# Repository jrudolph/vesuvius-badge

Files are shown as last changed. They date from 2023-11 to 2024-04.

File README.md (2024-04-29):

# Vesuvius First Word Badge - Hardware Design Files (for Kicad)

First Word Flickering

This repository contains the hardware design files for the Vesuvius First Word Badge badge that displays the first word found in burnt papyrus scrolls
analyzed for the [Vesuvius Challenge](https://scrollprize.substack.com/p/first-word-discovered-in-unopened).

Read more about the hardware of the badge in this [blog post](https://vesuvius.virtual-void.net/blog/2024/01/10/vesuvius-badge-hardware/). The Pico-based
firmware can be found in [vesuvius-badge-pico](https://github.com/jrudolph/vesuvius-badge-pico).

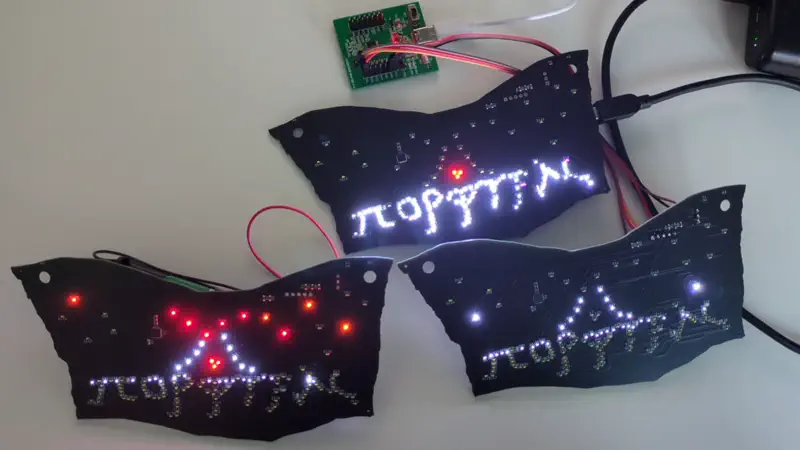
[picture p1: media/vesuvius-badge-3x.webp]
First Word Badge


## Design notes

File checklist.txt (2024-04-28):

 - footprints of leds
 - proper wiring of RPi
 - proper wiring of ch32v003
 - voltage parity between ch32v003 and is chip
 - check minimum voltage for white leds
 - check gerbers

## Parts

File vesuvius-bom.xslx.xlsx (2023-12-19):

Comment | Designator | Footprint | JLCPCB Part#(optional)
IS31FL3731-QF | U1 | QFN-28 | C191206
10uF | C1, C2 | 0402_C | C15525
100nF | C3 | 0402_C | C23024
10k | R1, R2, R3, R4 | 0603_R | C25804
15k | R5 | 0603_R | C22809
20k | R6 | 0603_R | C4184
white | D1-119 | 0402_LED | C917191
red | D120-129 | 0402_LED | C779449
purple | D130-139 | 0603_LED | C7371898
yellow | D140-144 | 0402_LED | C965796

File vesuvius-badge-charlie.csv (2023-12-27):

Comment | Designator | Footprint | LCSC
10uF | C1,C2 | Capacitor_SMD:C_0402_1005Metric | C15525
100nF | C3 | Capacitor_SMD:C_0402_1005Metric | C1525
LED white | D1,D2,D3,D4,D5,D6,D8,D9,D11,D12,D15,D17,D18,D20,D21,D22,D24,D25,D26,D27,D28,D29,D31,D33,D34,D35,D36,D37,D40,D41,D42,D44,D45,D47,D49,D50,D51,D53,D54,D55,D56,D57,D58,D59,D60,D61,D62,D63,D64,D66,D67,D68,D69,D70,D71,D72,D73,D74,D75,D76,D77,D79,D81,D82,D83,D84,D85,D86,D87,D89,D90,D91,D92,D93,D94,D95,D96,D97,D98,D99,D100,D101,D102,D103,D104,D105,D106,D108,D109,D110,D111,D112,D113,D114,D116,D117,D118,D119,D120,D121,D122,D123,D124,D125,D126,D127,D129,D130,D131,D132,D133,D134,D135,D136,D137,D138,D139,D140,D141,D143,D144 | LED_SMD:LED_0402_1005Metric | C965796
LED purple | D10,D13,D19,D38,D43,D52,D65,D88,D107,D115 | LED_SMD:LED_0603_1608Metric | C7371898
LED orange | D30,D39,D46,D78,D128 | LED_SMD:LED_0402_1005Metric | C779448
LED red | D7,D14,D16,D23,D32,D48,D80,D142 | LED_SMD:LED_0402_1005Metric | C779449
Fuse_Small | F1 | Fuse:Fuse_0402_1005Metric | C136320
MountingHole | H1,H2 | MountingHole:MountingHole_5.3mm_M5
Conn_01x05 | J1 | Connector_PinHeader_2.54mm:PinHeader_1x05_P2.54mm_Vertical
Conn_01x03 | J2 | Connector_PinHeader_2.54mm:PinHeader_1x03_P2.54mm_Vertical
SolderJumper_2_Open | JP1,JP3,JP4 | Jumper:SolderJumper-2_P1.3mm_Open_Pad1.0x1.5mm
SolderJumper_2_Bridged | JP2 | Jumper:SolderJumper-2_P1.3mm_Bridged_Pad1.0x1.5mm
4k7 | R1,R2 | Resistor_SMD:R_0603_1608Metric | C23162
10k | R3,R4 | Resistor_SMD:R_0603_1608Metric | C25804
15k | R5 | Resistor_SMD:R_0603_1608Metric | C22809
20k | R6 | Resistor_SMD:R_0603_1608Metric | C4184
IS31FL3731-QF | U1 | Package_DFN_QFN:QFN-28-1EP_4x4mm_P0.4mm_EP2.3x2.3mm | C191206
Pico | U2 | MCU_RaspberryPi_and_Boards:RPi_Pico_SMD
CH32V003J4M6 | U3 | Package_SO:SOP-8_3.9x4.9mm_P1.27mm

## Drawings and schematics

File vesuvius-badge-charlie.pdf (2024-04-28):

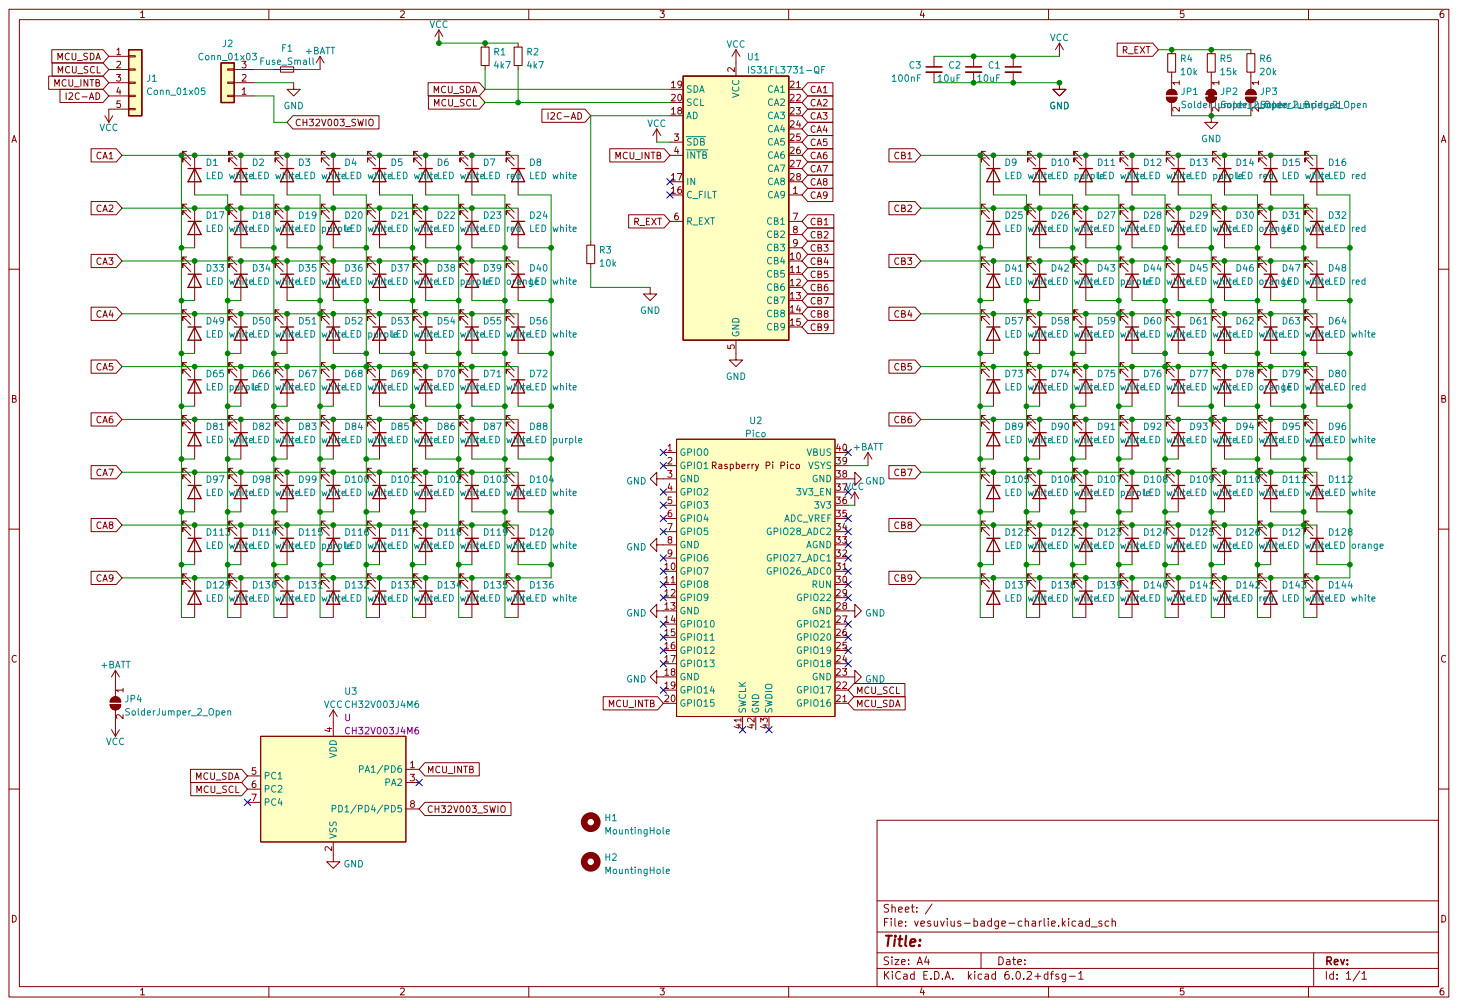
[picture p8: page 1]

2 SCL 20 CA1 21 CA2 22 CA3 23 CA4 24 CA5 25 CA6 26 CA7 27 CA8 28 ~{SDB} 3 ~{INTB} 4 GND

LED white GND GND

File: vesuvius-badge-charlie.kicad_sch Sheet: /
Id: 1/1 Title:

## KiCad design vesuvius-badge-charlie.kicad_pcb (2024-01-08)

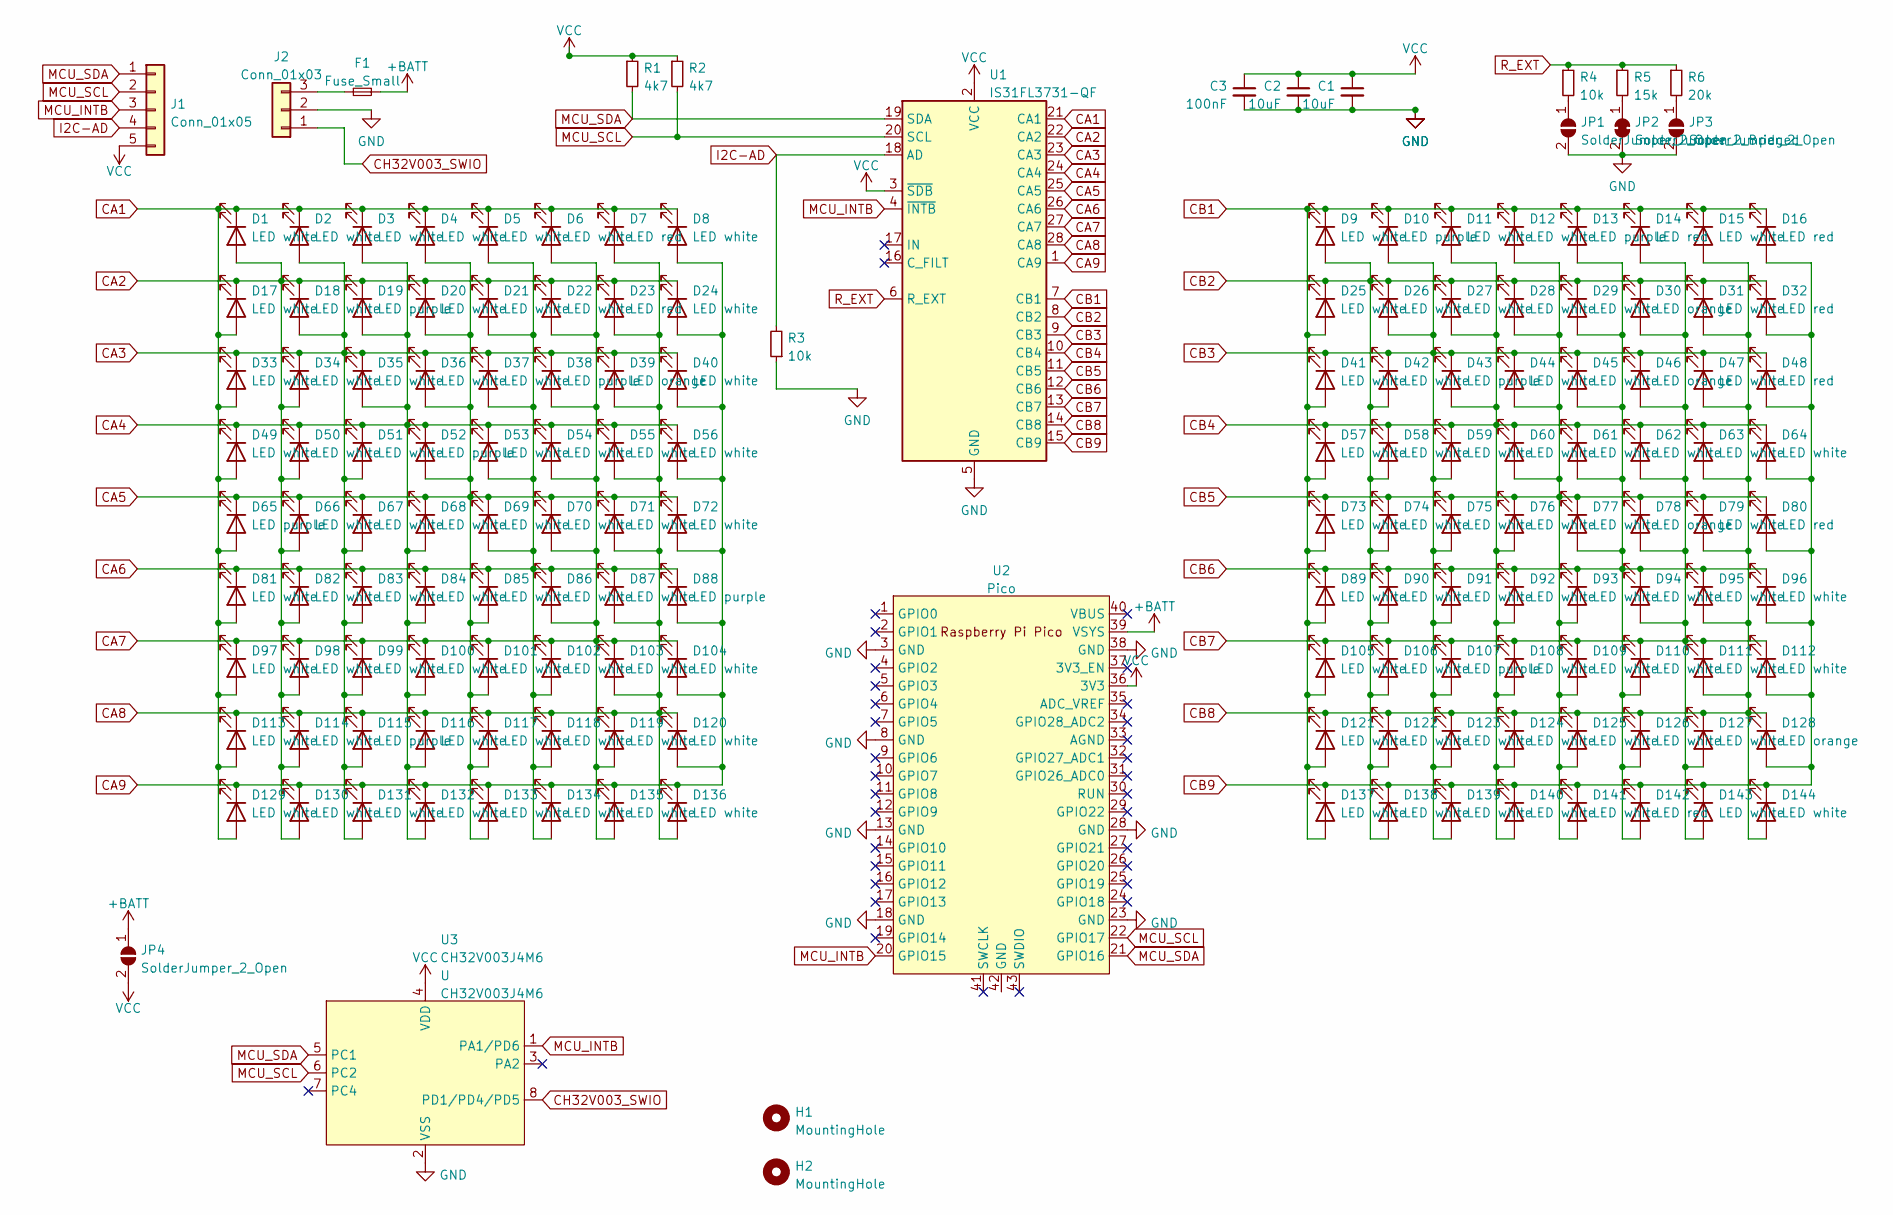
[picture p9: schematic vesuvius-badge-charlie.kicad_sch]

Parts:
C1, C2: 10uF; C_0402_1005Metric; LCSC C15525
C3: 100nF; C_0402_1005Metric; LCSC C1525
D1, D2, D3, D4, D5, D6, D8, D9, D11, D12, D15, D17, D18, D20, D21, D22, D24, D25, D26, D27, D28, D29, D31, D33, D34, D35, D36, D37, D40, D41, D42, D44, D45, D47, D49, D50, D51, D53, D54, D55, D56, D57, D58, D59, D60, D61, D62, D63, D64, D66, D67, D68, D69, D70, D71, D72, D73, D74, D75, D76, D77, D79, D81, D82, D83, D84, D85, D86, D87, D89, D90, D91, D92, D93, D94, D95, D96, D97, D98, D99, D100, D101, D102, D103, D104, D105, D106, D108, D109, D110, D111, D112, D113, D114, D116, D117, D118, D119, D120, D121, D122, D123, D124, D125, D126, D127, D129, D130, D131, D132, D133, D134, D135, D136, D137, D138, D139, D140, D141, D143, D144: LED white; LED_0402_1005Metric; LCSC C965796
D7, D14, D16, D23, D32, D48, D80, D142: LED red; LED_0402_1005Metric; LCSC C779449
D10, D13, D19, D38, D43, D52, D65, D88, D107, D115: LED purple; LED_0603_1608Metric; LCSC C7371898
D30, D39, D46, D78, D128: LED orange; LED_0402_1005Metric; LCSC C779448
F1: Fuse_Small; Fuse_0402_1005Metric; LCSC C136320
H1, H2: MountingHole; MountingHole_5.3mm_M5
J1: Conn_01x05; PinHeader_1x05_P2.54mm_Vertical
J2: Conn_01x03; PinHeader_1x03_P2.54mm_Vertical
JP1, JP3, JP4: SolderJumper_2_Open; SolderJumper-2_P1.3mm_Open_Pad1.0x1.5mm
JP2: SolderJumper_2_Bridged; SolderJumper-2_P1.3mm_Bridged_Pad1.0x1.5mm
R1, R2: 4k7; R_0603_1608Metric; LCSC C23162
R3, R4: 10k; R_0603_1608Metric; LCSC C25804
R5: 15k; R_0603_1608Metric; LCSC C22809
R6: 20k; R_0603_1608Metric; LCSC C4184
U1: IS31FL3731-QF; QFN-28-1EP_4x4mm_P0.4mm_EP2.3x2.3mm; LCSC C191206
U2: Pico; RPi_Pico_SMD
U3: CH32V003J4M6; SOP-8_3.9x4.9mm_P1.27mm

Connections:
+BATT: F1.2, JP4.1 (A), U2.39 (VSYS)
CA1: D1.1 (K), D2.1 (K), D3.1 (K), D4.1 (K), D5.1 (K), D6.1 (K), D7.1 (K), D8.1 (K), D17.2 (A), D33.2 (A), D49.2 (A), D65.2 (A), D81.2 (A), D97.2 (A), D113.2 (A), D129.2 (A), U1.21 (CA1)
CA2: D1.2 (A), D17.1 (K), D18.1 (K), D19.1 (K), D20.1 (K), D21.1 (K), D22.1 (K), D23.1 (K), D24.1 (K), D34.2 (A), D50.2 (A), D66.2 (A), D82.2 (A), D98.2 (A), D114.2 (A), D130.2 (A), U1.22 (CA2)
CA3: D2.2 (A), D18.2 (A), D33.1 (K), D34.1 (K), D35.1 (K), D36.1 (K), D37.1 (K), D38.1 (K), D39.1 (K), D40.1 (K), D51.2 (A), D67.2 (A), D83.2 (A), D99.2 (A), D115.2 (A), D131.2 (A), U1.23 (CA3)
CA4: D3.2 (A), D19.2 (A), D35.2 (A), D49.1 (K), D50.1 (K), D51.1 (K), D52.1 (K), D53.1 (K), D54.1 (K), D55.1 (K), D56.1 (K), D68.2 (A), D84.2 (A), D100.2 (A), D116.2 (A), D132.2 (A), U1.24 (CA4)
CA5: D4.2 (A), D20.2 (A), D36.2 (A), D52.2 (A), D65.1 (K), D66.1 (K), D67.1 (K), D68.1 (K), D69.1 (K), D70.1 (K), D71.1 (K), D72.1 (K), D85.2 (A), D101.2 (A), D117.2 (A), D133.2 (A), U1.25 (CA5)
CA6: D5.2 (A), D21.2 (A), D37.2 (A), D53.2 (A), D69.2 (A), D81.1 (K), D82.1 (K), D83.1 (K), D84.1 (K), D85.1 (K), D86.1 (K), D87.1 (K), D88.1 (K), D102.2 (A), D118.2 (A), D134.2 (A), U1.26 (CA6)
CA7: D6.2 (A), D22.2 (A), D38.2 (A), D54.2 (A), D70.2 (A), D86.2 (A), D97.1 (K), D98.1 (K), D99.1 (K), D100.1 (K), D101.1 (K), D102.1 (K), D103.1 (K), D104.1 (K), D119.2 (A), D135.2 (A), U1.27 (CA7)
CA8: D7.2 (A), D23.2 (A), D39.2 (A), D55.2 (A), D71.2 (A), D87.2 (A), D103.2 (A), D113.1 (K), D114.1 (K), D115.1 (K), D116.1 (K), D117.1 (K), D118.1 (K), D119.1 (K), D120.1 (K), D136.2 (A), U1.28 (CA8)
CA9: D8.2 (A), D24.2 (A), D40.2 (A), D56.2 (A), D72.2 (A), D88.2 (A), D104.2 (A), D120.2 (A), D129.1 (K), D130.1 (K), D131.1 (K), D132.1 (K), D133.1 (K), D134.1 (K), D135.1 (K), D136.1 (K), U1.1 (CA9)
CB1: D9.1 (K), D10.1 (K), D11.1 (K), D12.1 (K), D13.1 (K), D14.1 (K), D15.1 (K), D16.1 (K), D25.2 (A), D41.2 (A), D57.2 (A), D73.2 (A), D89.2 (A), D105.2 (A), D121.2 (A), D137.2 (A), U1.7 (CB1)
CB2: D9.2 (A), D25.1 (K), D26.1 (K), D27.1 (K), D28.1 (K), D29.1 (K), D30.1 (K), D31.1 (K), D32.1 (K), D42.2 (A), D58.2 (A), D74.2 (A), D90.2 (A), D106.2 (A), D122.2 (A), D138.2 (A), U1.8 (CB2)
CB3: D10.2 (A), D26.2 (A), D41.1 (K), D42.1 (K), D43.1 (K), D44.1 (K), D45.1 (K), D46.1 (K), D47.1 (K), D48.1 (K), D59.2 (A), D75.2 (A), D91.2 (A), D107.2 (A), D123.2 (A), D139.2 (A), U1.9 (CB3)
CB4: D11.2 (A), D27.2 (A), D43.2 (A), D57.1 (K), D58.1 (K), D59.1 (K), D60.1 (K), D61.1 (K), D62.1 (K), D63.1 (K), D64.1 (K), D76.2 (A), D92.2 (A), D108.2 (A), D124.2 (A), D140.2 (A), U1.10 (CB4)
CB5: D12.2 (A), D28.2 (A), D44.2 (A), D60.2 (A), D73.1 (K), D74.1 (K), D75.1 (K), D76.1 (K), D77.1 (K), D78.1 (K), D79.1 (K), D80.1 (K), D93.2 (A), D109.2 (A), D125.2 (A), D141.2 (A), U1.11 (CB5)
CB6: D13.2 (A), D29.2 (A), D45.2 (A), D61.2 (A), D77.2 (A), D89.1 (K), D90.1 (K), D91.1 (K), D92.1 (K), D93.1 (K), D94.1 (K), D95.1 (K), D96.1 (K), D110.2 (A), D126.2 (A), D142.2 (A), U1.12 (CB6)
CB7: D14.2 (A), D30.2 (A), D46.2 (A), D62.2 (A), D78.2 (A), D94.2 (A), D105.1 (K), D106.1 (K), D107.1 (K), D108.1 (K), D109.1 (K), D110.1 (K), D111.1 (K), D112.1 (K), D127.2 (A), D143.2 (A), U1.13 (CB7)
CB8: D15.2 (A), D31.2 (A), D47.2 (A), D63.2 (A), D79.2 (A), D95.2 (A), D111.2 (A), D121.1 (K), D122.1 (K), D123.1 (K), D124.1 (K), D125.1 (K), D126.1 (K), D127.1 (K), D128.1 (K), D144.2 (A), U1.14 (CB8)
CB9: D16.2 (A), D32.2 (A), D48.2 (A), D64.2 (A), D80.2 (A), D96.2 (A), D112.2 (A), D128.2 (A), D137.1 (K), D138.1 (K), D139.1 (K), D140.1 (K), D141.1 (K), D142.1 (K), D143.1 (K), D144.1 (K), U1.15 (CB9)
CH32V003_SWIO: J2.1, U3.8 (PD1/PD4/PD5)
GND: C1.2, C2.2, C3.2, J2.2, JP1.2 (B), JP2.2 (B), JP3.2 (B), R3.1, U1.5 (GND), U1.29 (GND), U2.3 (GND), U2.8 (GND), U2.13 (GND), U2.18 (GND), U2.23 (GND), U2.28 (GND), U2.38 (GND), U3.2 (VSS)
I2C-AD: J1.4, R3.2, U1.18 (AD)
MCU_INTB: J1.3, U1.4 (~INTB), U2.20 (GPIO15), U3.1 (PA1/PD6)
MCU_SCL: J1.2, R2.2, U1.20 (SCL), U2.22 (GPIO17), U3.6 (PC2)
MCU_SDA: J1.1, R1.2, U1.19 (SDA), U2.21 (GPIO16), U3.5 (PC1)
unnamed: F1.1, J2.3
unnamed: JP1.1 (A), R4.2
unnamed: JP2.1 (A), R5.2
unnamed: JP3.1 (A), R6.2
R_EXT: R4.1, R5.1, R6.1, U1.6 (R_EXT)
VCC: C1.1, C2.1, C3.1, J1.5, JP4.2 (B), R1.1, R2.1, U1.2 (VCC), U1.3 (~SDB), U2.36 (3V3), U3.4 (VDD)

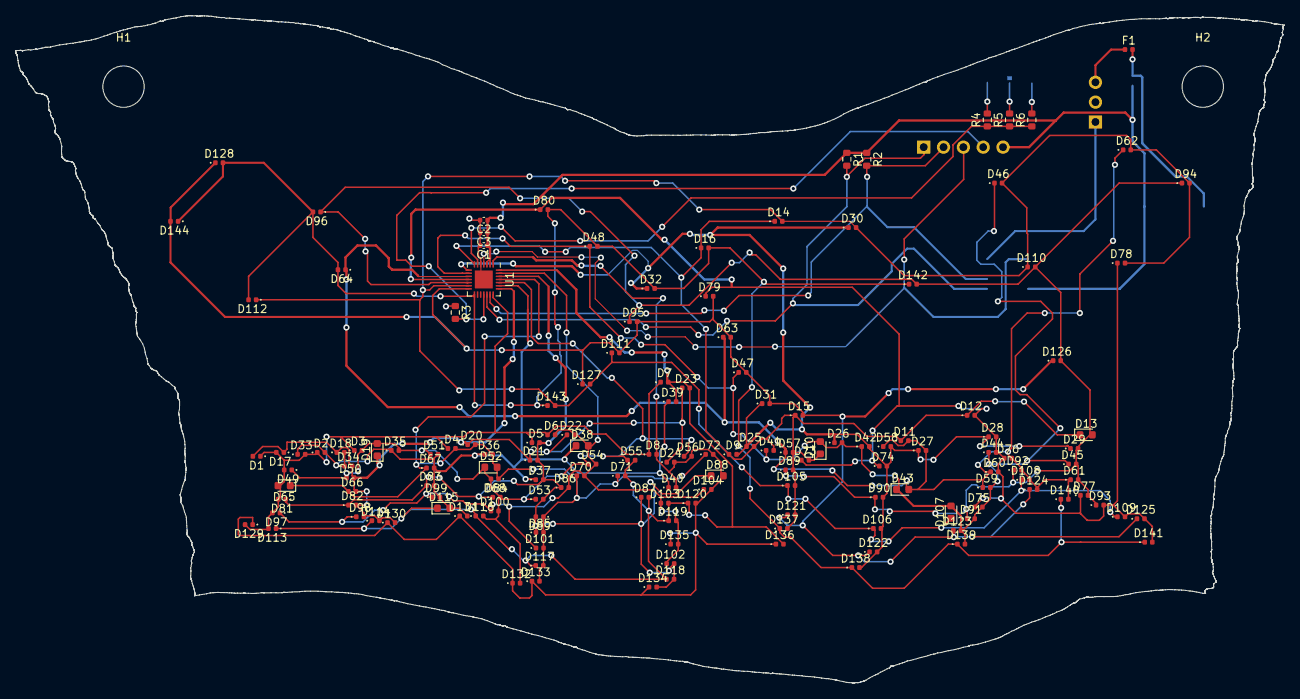
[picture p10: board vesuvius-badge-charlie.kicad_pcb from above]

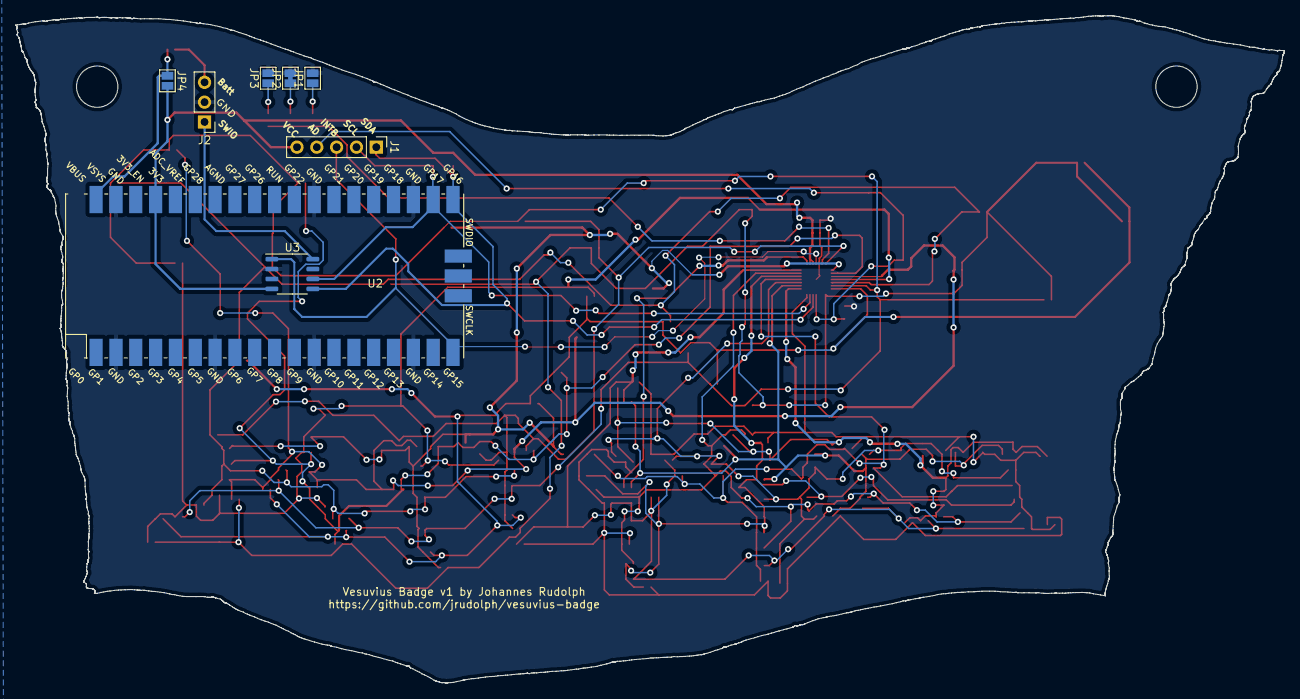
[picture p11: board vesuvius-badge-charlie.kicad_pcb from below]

Board: 2 copper layers, 162.5 x 85.5 mm, 165 parts (8 on the bottom side), 31 nets.

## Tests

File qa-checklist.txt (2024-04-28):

 - visual solder inspection
 - clean
 - function test

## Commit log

2023-11-24 basic setup
    [vesuvius-badge.kicad_pcb, vesuvius-badge.kicad_sch]
2023-11-24 some routing done
    [vesuvius-badge.kicad_pcb]
2023-11-27 setup new badge based on IS31FL3731
    [vesuvius-badge-charlie.kicad_pcb, vesuvius-badge-charlie.kicad_sch]
2023-11-29 letters and vesuvius
    [vesuvius-badge-charlie.kicad_pcb, vesuvius-badge-charlie.kicad_sch]
2023-12-02 letters done, now the rest of the wiring
    [vesuvius-badge-charlie.kicad_pcb, vesuvius-badge-charlie.kicad_sch]
2023-12-02 routing mostly dnoe
    [vesuvius-badge-charlie.kicad_pcb]
2023-12-02 wiring done
    [vesuvius-badge-charlie.kicad_pcb, vesuvius-badge-charlie.kicad_sch]
2023-12-07 create wider tracks near the driver for long nets
2023-12-19 before applying purple diode footprint resize
    [vesuvius-badge-charlie.kicad_sch, vesuvius-bom.xslx.xlsx]
2023-12-19 redo pcb after led footprint change
    [vesuvius-badge-charlie.kicad_pcb]
2023-12-20 finished functional parts
    [vesuvius-badge-charlie.kicad_pcb, vesuvius-badge-charlie.kicad_sch]
2023-12-27 final files and gerbers as submitted to production
    [vesuvius-badge-charlie-B_Cu.gbl, vesuvius-badge-charlie-B_Mask.gbs, vesuvius-badge-charlie-B_Paste.gbp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]
2023-12-27 gerber screenshot teaser
2024-01-08 latest changes
    [vesuvius-badge-charlie.kicad_pcb]
2024-04-28 move the real design to main directory, remove old design
    [vesuvius-badge-charlie-B_Cu.gbl, vesuvius-badge-charlie-B_Mask.gbs, vesuvius-badge-charlie-B_Paste.gbp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]
2024-04-28 add v1 final schematics pdf
